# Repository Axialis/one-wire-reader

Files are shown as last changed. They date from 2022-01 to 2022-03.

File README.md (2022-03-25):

# One-Wire-Reader
One Wire Reader for 8 DS18B20 sensors on DS2482-100 (Maxim Integrated).
Addresses are written to non-volatile memory 

Schematic (KiCad):
OneWireReader

Photo:



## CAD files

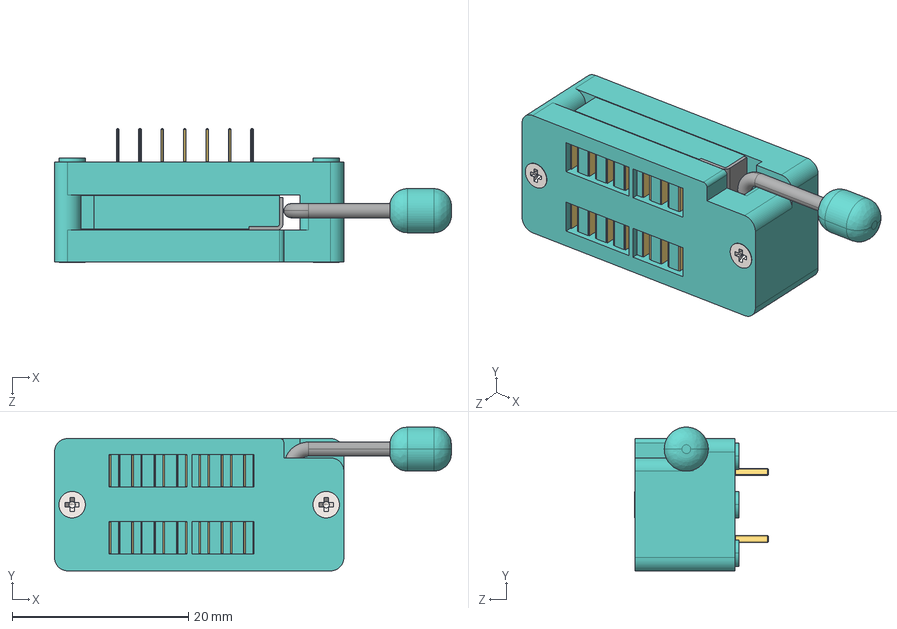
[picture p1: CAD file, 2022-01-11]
HW/3Dmodels/ZIF-Socket-14-pin.STEP
45.0 x 16.3 x 15.2 mm
Screw-002
Screw-001
Push-Bar
User_Library-ZIFF_14_Fillet008
User_Library-ZIFF_14_Fillet007
User_Library-ZIFF_14_Fusion008
User_Library-ZIFF_14_Cut002

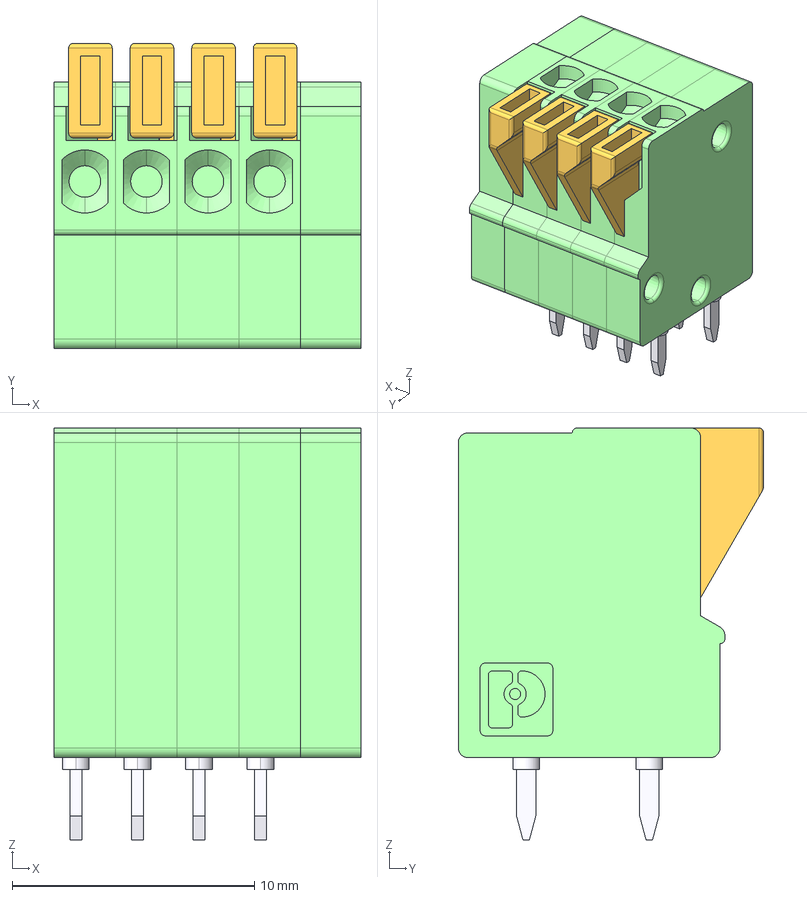
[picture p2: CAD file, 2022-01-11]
HW/3Dmodels/pxc_1789595_02_FFKDSA1-V-2-54-4_3D.stp
12.7 x 12.6 x 17.0 mm
ffkds-v-2.54.2 x 4
dkl-ffkds

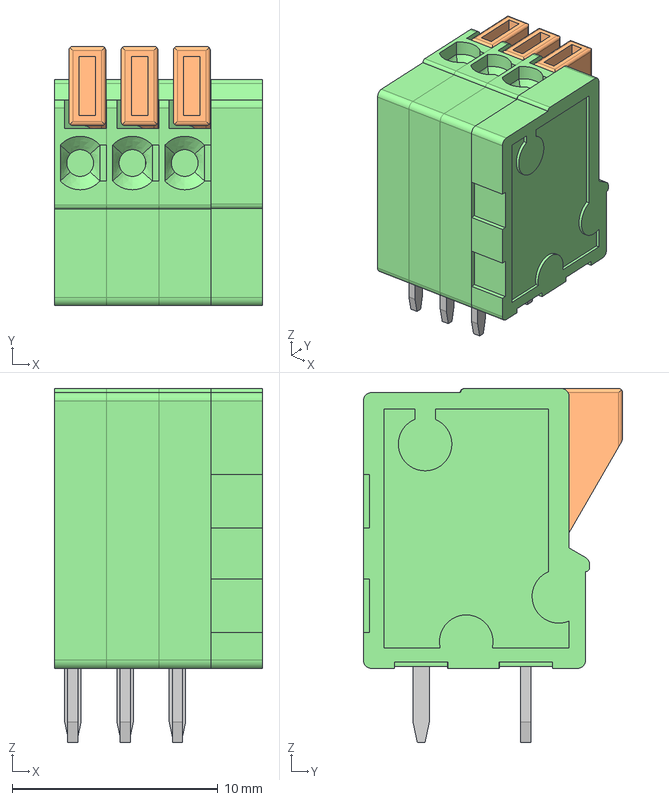
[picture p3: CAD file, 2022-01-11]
HW/3Dmodels/pxc_1789320_02_FFKDSA1-V-2-54-3_3D.stp
10.1 x 12.6 x 17.2 mm
LP_FFKDS_V_2_54_3_60.1.2 x 6
AC_FFKDS_2_54_WIPPE x 3
PK_FFKDS_V_2_54_GEH x 3
DK_D_FFKDS_2_54_DKL

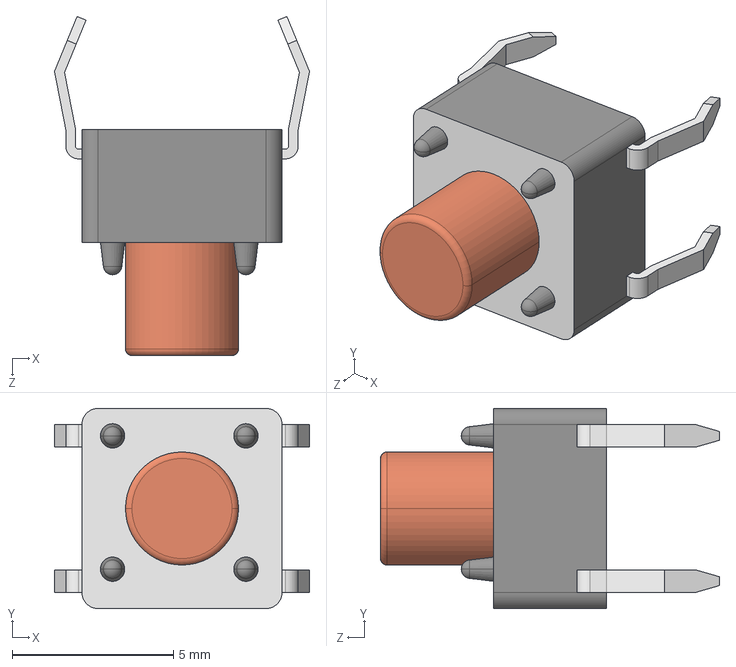
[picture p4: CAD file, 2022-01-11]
HW/3Dmodels/tactile dts-63k.step
7.90 x 6.20 x 10.5 mm

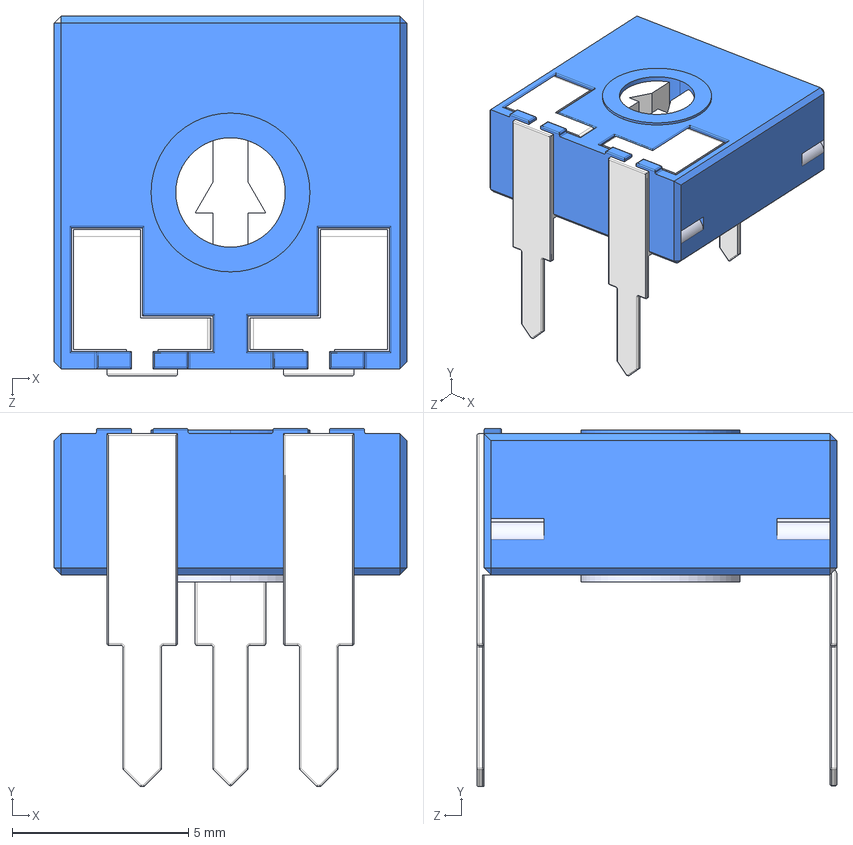
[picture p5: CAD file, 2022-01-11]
HW/3Dmodels/CA9V.step
10.0 x 10.2 x 10.2 mm

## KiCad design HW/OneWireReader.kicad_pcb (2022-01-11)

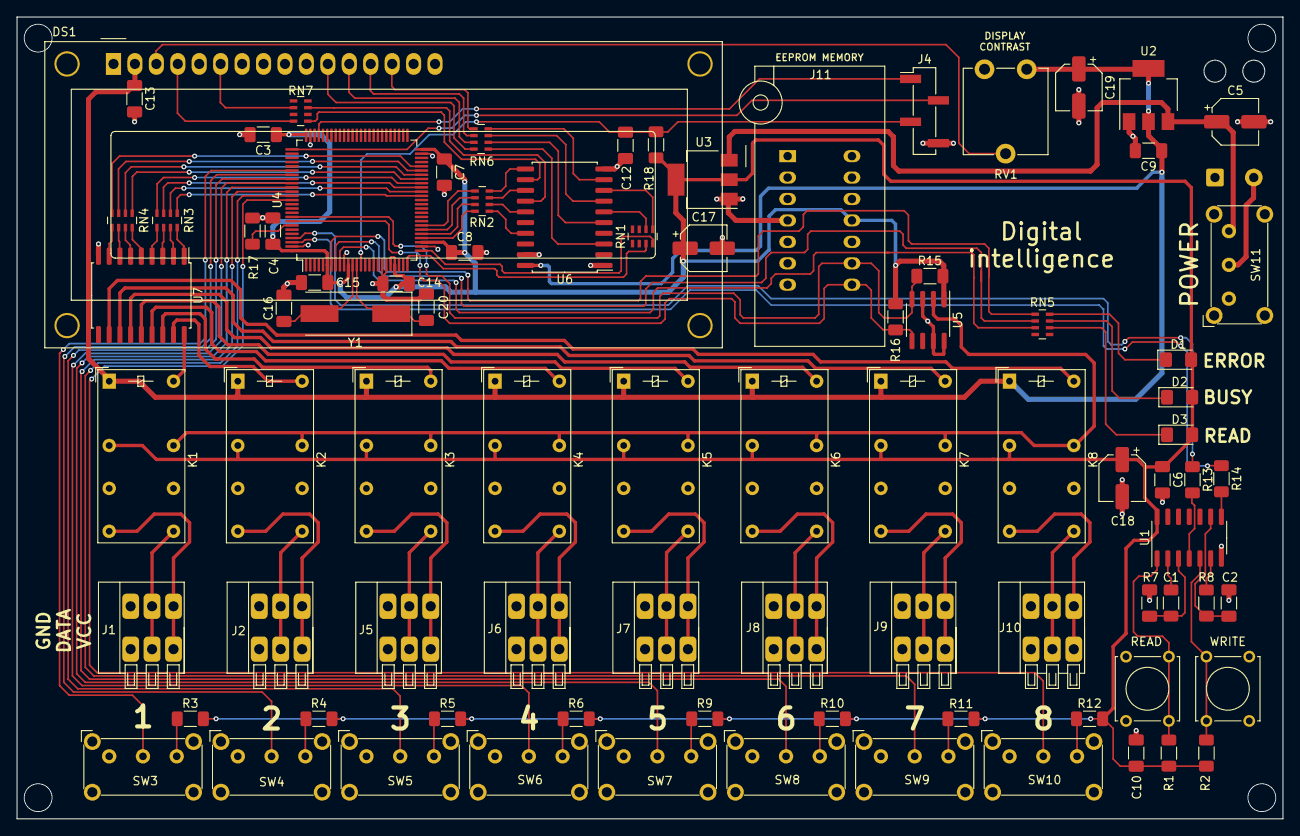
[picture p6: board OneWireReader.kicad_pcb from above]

Board: 2 copper layers, 150.0 x 95.0 mm, 87 parts (1 on the bottom side), 111 nets.

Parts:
C1, C2, C3, C4, C6, C7, C8, C9, C10, C12, C13, C14, C15: 100n; C_1206_3216Metric_Pad1.33x1.80mm_HandSolder
C5, C17, C18, C19: 10uF x16V; CP_Elec_5x5.4
C16, C20: 22p; C_1206_3216Metric_Pad1.33x1.80mm_HandSolder
D1, D2, D3: LED; LED_1206_3216Metric_Pad1.42x1.75mm_HandSolder
DS1: WC1602A
J1, J2, J5, J6, J7, J8, J9, J10: DG141V-2.54-03P-14-00A(H)
J3: Wire; SolderWire-0.5sqmm_1x02_P4.6mm_D0.9mm_OD2.1mm_Relief
J4: Programming; PinHeader_1x04_P2.54mm_Vertical_SMD_Pin1Left
J11: ZIF-14 KLS7-SK-22H13-1-S; DIP_Socket-14_W4.3_W5.08_W7.62_W10.16_W10.9_3M_214-3339-00-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
K1, K2, K3, K4, K5, K6, K7, K8: HFD2/005-S-D(FINDER-30.22); Relay_DPDT_Finder_30.22
R1, R2, R3, R4, R5, R6, R9, R10, R11, R12, R15, R16: 4k7; R_1206_3216Metric_Pad1.30x1.75mm_HandSolder
R7, R8, R13, R14: 220; R_1206_3216Metric_Pad1.30x1.75mm_HandSolder
R17, R18: 100k; R_1206_3216Metric_Pad1.30x1.75mm_HandSolder
READ: SW_Push; SW_Tactile_Straight_KSL0Axx1LFTR
RN1, RN2, RN3, RN4, RN5, RN6, RN7: 220; R_Array_Concave_4x0603
RV1: 10k; Potentiometer_ACP_CA9-V10_Vertical
SW3, SW4, SW5, SW6, SW7, SW8, SW9, SW10, SW11: KLS7-SK-22H13-1-S; SW_E-Switch_EG1224_SPDT_Angled
U1: 74HC14; SO-14_3.9x8.65mm_P1.27mm
U2: AZ1117-5.0; SOT-223-3_TabPin2
U3: AZ1117-3.3; SOT-223-3_TabPin2
U4: STM32F105VCTx; LQFP-100_14x14mm_P0.5mm
U5: DS2482S-100; SOIC-8_3.9x4.9mm_P1.27mm
U6: 74HCT244; SOIC-20W_7.5x12.8mm_P1.27mm
U7: ULN2803A; SOIC-18W_7.5x11.6mm_P1.27mm
WRITE: SW_Push; SW_Tactile_Straight_KSL0Axx1LFTR
Y1: 8MHz; Crystal_SMD_HC49-SD

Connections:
3V3: C3.1, C4.1, C6.1, C7.1, C8.1, C10.1, C14.1, C15.1, C17.1, C18.1, D1.2, D2.2, D3.2, J11.11, K1.11, K2.11, K3.11, K4.11, K5.11, K6.11, K7.11, K8.11, R1.2, R2.2, R3.2, R4.2, R5.2, R6.2, R9.2, R10.2, R11.1, R12.2, R15.2, R16.2, R18.2, U1.14, U3.2, U4.6, U4.11, U4.21, U4.22, U4.28, U4.50, U4.75, U4.100, U5.1
5V: C9.1, C13.1, C19.1, DS1.2, K1.A1, K2.A1, K3.A1, K4.A1, K5.A1, K6.A1, K7.A1, K8.A1, RV1.3, U2.2, U6.20
/BOOT: R17.2, U4.94
/BTN_1: R13.1, U4.97
/BTN_2: R14.1, U4.98
/DS_1: RN3.1, U4.39
/DS_2: RN3.2, U4.40
/DS_3: RN3.3, U4.41
/DS_4: RN3.4, U4.42
/DS_5: RN4.1, U4.43
/DS_6: RN4.2, U4.44
/DS_7: RN4.3, U4.45
/DS_8: RN4.4, U4.46
/NRST: C12.1, J4.3, R18.1, U4.14
/OSC1: C16.1, U4.12, Y1.2
/OSC2: C20.1, U4.13, Y1.1
/OneWire: K1.21, K2.21, K3.21, K4.21, K5.21, K6.21, K7.21, K8.21, U5.2
/Rel_1: K1.A2, U7.18
/Rel_2: K2.A2, U7.17
/Rel_3: K3.A2, U7.16
/Rel_4: K4.A2, U7.15
/Rel_5: K5.A2, U7.14
/Rel_6: K6.A2, U7.13
/Rel_7: K7.A2, U7.12
/Rel_8: K8.A2, U7.11
/SCL: J11.9, R15.1, U4.92, U5.4
/SDA: J11.8, R16.1, U4.93, U5.5
/SNS_1: SW3.2, U4.81
/SNS_2: SW4.2, U4.82
/SNS_3: SW5.2, U4.83
/SNS_4: SW6.2, U4.84
/SNS_5: SW7.2, U4.85
/SNS_6: SW8.2, U4.86
/SNS_7: SW9.2, U4.87
/SNS_8: SW10.2, U4.88
/SWCLK: J4.2, U4.76
/SWDIO: J4.1, U4.72
GND: C1.1, C2.1, C3.2, C4.2, C5.2, C6.2, C7.2, C8.2, C9.2, C10.2, C12.2, C13.2, C14.2, C15.2, C16.2, C17.2, C18.2, C19.2, C20.2, DS1.1, DS1.5, J1.3, J2.3, J3.1, J4.4, J5.3, J6.3, J7.3, J8.3, J9.3, J10.3, J11.4, J11.5, J11.6, J11.7, J11.10, R17.1, READ.1, RV1.1, SW3.1, SW4.1, SW5.1, SW6.1, SW7.1, SW8.1, SW9.1, SW10.1, U1.7, U2.1, U3.1, U4.10, U4.19, U4.20, U4.27, U4.49, U4.74, U4.99, U5.3, U5.7, U5.8, U6.1, U6.10, U6.19, U7.9, WRITE.1
unnamed: C1.2, R7.1, U1.3
unnamed: C2.2, R8.1, U1.9
unnamed: C5.1, SW11.3, U2.3, U3.3
unnamed: D1.1, RN5.8
unnamed: D2.1, RN5.7
unnamed: D3.1, RN5.6
unnamed: DS1.3, RV1.2
unnamed: DS1.4, RN7.8
unnamed: DS1.6, RN7.6
unnamed: DS1.11, RN6.8
unnamed: DS1.12, RN6.7
unnamed: DS1.13, RN6.6
unnamed: DS1.14, RN6.5
unnamed: J1.1, K1.14
unnamed: J1.2, K1.24
unnamed: J2.1, K2.14
unnamed: J2.2, K2.24
unnamed: J3.2, SW11.2
unnamed: J5.1, K3.14
unnamed: J5.2, K3.24
unnamed: J6.1, K4.14
unnamed: J6.2, K4.24
unnamed: J7.1, K5.14
unnamed: J7.2, K5.24
unnamed: J8.1, K6.14
unnamed: J8.2, K6.24
unnamed: J9.1, K7.14
unnamed: J9.2, K7.24
unnamed: J10.1, K8.14
unnamed: J10.2, K8.24
unnamed: R1.1, READ.2, U1.1
unnamed: R2.1, U1.5, WRITE.2
unnamed: R3.1, SW3.3
unnamed: R4.1, SW4.3
unnamed: R5.1, SW5.3
unnamed: R6.1, SW6.3
unnamed: R7.2, U1.2
unnamed: R8.2, U1.6
unnamed: R9.1, SW7.3
unnamed: R10.1, SW8.3
unnamed: R11.2, SW9.3
unnamed: R12.1, SW10.3
unnamed: R13.2, U1.4
unnamed: R14.2, U1.8
unnamed: RN1.3, U4.25
unnamed: RN1.4, U4.26
unnamed: RN1.5, U6.8
unnamed: RN1.6, U6.6
unnamed: RN2.1, U4.32
unnamed: RN2.2, U4.31
unnamed: RN2.3, U4.30
unnamed: RN2.4, U4.29
unnamed: RN2.5, U6.17
unnamed: RN2.6, U6.15
unnamed: RN2.7, U6.13
unnamed: RN2.8, U6.11
unnamed: RN3.5, U7.4
unnamed: RN3.6, U7.3
unnamed: RN3.7, U7.2
unnamed: RN3.8, U7.1
unnamed: RN4.5, U7.8
unnamed: RN4.6, U7.7
unnamed: RN4.7, U7.6
unnamed: RN4.8, U7.5
unnamed: RN5.1, U4.7
unnamed: RN5.2, U4.8
unnamed: RN5.3, U4.9
unnamed: RN6.1, U6.3
unnamed: RN6.2, U6.5
unnamed: RN6.3, U6.7
unnamed: RN6.4, U6.9
unnamed: RN7.1, U6.12
unnamed: RN7.3, U6.14

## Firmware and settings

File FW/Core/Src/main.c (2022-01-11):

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
/* Includes ------------------------------------------------------------------*/
#include "main.h"
#include "i2c.h"
#include "gpio.h"

/* USER CODE BEGIN Includes */
#include "lcd.h"
#include "macro.h"
#include "memory.h"
#include "DS2482.h"



/* USER CODE END Includes */


void SystemClock_Config(void);
/* USER CODE BEGIN PFP */
void ErrorLed(uint8_t status);
void BusyLed(uint8_t status);
void ReadLed(uint8_t status);
void SelectChannels();
void DrawSelectChannel();
void DrawAnimation();
void RelayControl();
void Rel(int number);
void WriteMemory();
void ReadOWDevice();
void AddressMenu(uint8_t channel);
void StatusPercent(uint8_t per);
uint8_t LinePosition(uint8_t ch);

/* USER CODE END PFP */

/* USER CODE BEGIN 0 */
typedef enum
{
	ON = 1,
	OFF = 0
} LedState;


Lcd_HandleTypeDef lcd;



uint8_t channel[7];
uint8_t sensor[8][8] = {0x00};
uint8_t key = 0;
uint8_t menuposstart = 0;

/* USER CODE END 0 */

/**
 * @brief  The application entry point.
 * @retval int
 */
int main(void)
{
	/* MCU Configuration--------------------------------------------------------*/

	/* Reset of all peripherals, Initializes the Flash interface and the Systick. */
	HAL_Init();

	/* Configure the system clock */
	SystemClock_Config();

	/* Initialize all configured peripherals */
	MX_GPIO_Init();
	MX_I2C1_Init();
	/* USER CODE BEGIN 2 */
	HAL_Delay(100);
	Lcd_PortType ports[] = {
			D4_GPIO_Port, D5_GPIO_Port, D6_GPIO_Port, D7_GPIO_Port
	};

	Lcd_PinType pins[] = {D4_Pin, D5_Pin, D6_Pin, D7_Pin};



	lcd = Lcd_create(ports, pins, RS_GPIO_Port, RS_Pin, E_GPIO_Port, E_Pin, LCD_4_BIT_MODE);

	Lcd_cursor(&lcd, 0,3);
	Lcd_string(&lcd, "TENDO 4/8");
	Lcd_cursor(&lcd, 1,0);
	Lcd_string(&lcd, "ONE WIRE READER");


	Lcd_clear(&lcd);

	DS2842Reset();
	DS2842Configuration();

	ErrorLed(OFF);
	BusyLed(OFF);
	ReadLed(OFF);


	/* USER CODE END 2 */

	/* Infinite loop */
	/* USER CODE BEGIN WHILE */
	while (1)
	{
		/* USER CODE END WHILE */

		/* USER CODE BEGIN 3 */

		switch (key) {
		case 0:

			Lcd_cursor(&lcd, 0,0);
			Lcd_string(&lcd, "SELECT CHANNELS");
			SelectChannels();
			DrawSelectChannel();
			if(HAL_GPIO_ReadPin(GPIOE, GPIO_PIN_0) == 0) //read
			{
				key = 1;
			}

			if(HAL_GPIO_ReadPin(GPIOE, GPIO_PIN_1) == 0) //write
			{
				key = 9;
			}

			break;

		case 1:
			Lcd_clear(&lcd);
			key = 2;
			break;

		case 2:
			DrawAnimation();
			key = 5;
			break;

		case 3:
			Lcd_clear(&lcd);
			key = 4;
			break;

		case 4:
			DrawAnimation();
			key = 7;
			break;

		case 5:
			Lcd_clear(&lcd);
			key = 6;
			break;

		case 6:
			Lcd_cursor(&lcd, 0,0);
			Lcd_string(&lcd, "Press READ to");
			Lcd_cursor(&lcd, 1,0);
			Lcd_string(&lcd, "continue");
			for(;;)
			{
				Lcd_cursor(&lcd, 1,15);
				Lcd_string(&lcd, ">");
				if(HAL_GPIO_ReadPin(GPIOE, GPIO_PIN_0) == 0) //read
				{
					ReadOWDevice();
					key = 7;
					break;
				}
				HAL_Delay(150);
				Lcd_cursor(&lcd, 1,15);
				Lcd_string(&lcd, " ");
				if(HAL_GPIO_ReadPin(GPIOE, GPIO_PIN_0) == 0) //read
				{
					ReadOWDevice();
					key = 7;
					break;
				}
				HAL_Delay(150);
			}

			break;

		case 7:
			AddressMenu(menuposstart);
			key = 8;
			break;

		case 8:

			if(HAL_GPIO_ReadPin(GPIOE, GPIO_PIN_0) == 0) //<R
			{
				if(menuposstart != 0)
				{
					HAL_Delay(150);
					menuposstart = menuposstart - 1;
					key = 7;
				}
			}

			if(HAL_GPIO_ReadPin(GPIOE, GPIO_PIN_1) == 0) //W>
			{
				if(menuposstart != 9)
				{
					HAL_Delay(150);
					menuposstart = menuposstart + 1;
					key = 7;
				}
				if(menuposstart == 9)
				{
					menuposstart = 0;
					Lcd_clear(&lcd);
					for(int k = 0; k<8; k++)
					{
						for(int m = 0; m<8; m++)
						{
							sensor[k][m] = 0;
						}
					}
					key = 0;
				}
			}
			break;
			//-----------------------------------------------------WRITE TO MEMORY--------------------------------------------//
		case 9:
			Lcd_clear(&lcd);
			key = 10;
			break;

		case 10:
			Lcd_cursor(&lcd, 0,0);
			Lcd_string(&lcd, "Insert IC memory ");
			Lcd_cursor(&lcd, 1,0);
			Lcd_string(&lcd, "and press WRITE");
			for(;;)
			{
				Lcd_cursor(&lcd, 1,15);
				Lcd_string(&lcd, ">");
				if(HAL_GPIO_ReadPin(GPIOE, GPIO_PIN_1) == 0) //write
				{
					key = 11;
					break;
				}
				HAL_Delay(150);
				Lcd_cursor(&lcd, 1,15);
				Lcd_string(&lcd, " ");
				if(HAL_GPIO_ReadPin(GPIOE, GPIO_PIN_1) == 0) //write
				{
					key = 11;
					break;
				}
				HAL_Delay(150);
			}
			break;

		case 11:
			Lcd_clear(&lcd);
			key = 12;
			break;

		case 12:

			if(HAL_I2C_IsDeviceReady(&hi2c1, 0xA0, 1, HAL_MAX_DELAY) != HAL_OK)
			{
				ErrorLed(ON);
				Lcd_cursor(&lcd, 0,0);
				Lcd_string(&lcd, "NO MEMORY IC");
				Lcd_cursor(&lcd, 1,0);
				Lcd_string(&lcd, "Check slot");
				key = 13;
			}
			else
			{
				ErrorLed(OFF);
				key = 15;
			}
			break;

		case 13:

			if(HAL_I2C_IsDeviceReady(&hi2c1, 0xA0, 1, HAL_MAX_DELAY) != HAL_OK)
			{
				key = 12;
			}
			else
			{
				key = 14;
			}
			break;

		case 14:
			Lcd_clear(&lcd);
			key = 15;
			break;

		case 15:
			ErrorLed(OFF);
			Lcd_cursor(&lcd, 0,0);
			Lcd_string(&lcd, "OK");
			Lcd_cursor(&lcd, 1,0);
			Lcd_string(&lcd, "Press WRITE");
			for(;;)
			{
				Lcd_cursor(&lcd, 1,15);
				Lcd_string(&lcd, ">");
				if(HAL_GPIO_ReadPin(GPIOE, GPIO_PIN_1) == 0) //read
				{
					key = 16;
					break;
				}
				HAL_Delay(150);
				Lcd_cursor(&lcd, 1,15);
				Lcd_string(&lcd, " ");
				if(HAL_GPIO_ReadPin(GPIOE, GPIO_PIN_1) == 0) //read
				{
					key = 16;
					break;
				}
				HAL_Delay(150);
			}
			break;

		case 16:
			Lcd_clear(&lcd);
			key = 17;
			break;

		case 17:
			ReadOWDevice();
			WriteMemory();
			key = 18;
			break;

		case 18:
			Lcd_clear(&lcd);
			Lcd_cursor(&lcd, 0,0);
			Lcd_string(&lcd, "OK! Press 'W' to");
			Lcd_cursor(&lcd, 1,0);
			Lcd_string(&lcd, "return Main Menu");
			key = 19;
			break;

		case 19:
				if(HAL_GPIO_ReadPin(GPIOE, GPIO_PIN_1) == 0) //read
				{
					Lcd_clear(&lcd);
					key = 0;
					break;
				}
			break;


		}

	}
	/* USER CODE END 3 */
}

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
/* USER CODE BEGIN 4 */

void ErrorLed(uint8_t status)
{
	if(status == 0)
	{
		HAL_GPIO_WritePin(GPIOC, GPIO_PIN_13, GPIO_PIN_SET);
	}
	else
	{
		HAL_GPIO_WritePin(GPIOC, GPIO_PIN_13, GPIO_PIN_RESET);
	}
}

void BusyLed(uint8_t status)
{
	if(status == 0)
	{
		HAL_GPIO_WritePin(GPIOC, GPIO_PIN_14, GPIO_PIN_SET);
	}
	else
	{
		HAL_GPIO_WritePin(GPIOC, GPIO_PIN_14, GPIO_PIN_RESET);
	}
}

void ReadLed(uint8_t status)
{
	if(status == 0)
	{
		HAL_GPIO_WritePin(GPIOC, GPIO_PIN_15, GPIO_PIN_SET);
	}
	else
	{
		HAL_GPIO_WritePin(GPIOC, GPIO_PIN_15, GPIO_PIN_RESET);
	}
}

void SelectChannels()
{
	if(HAL_GPIO_ReadPin(GPIOD, GPIO_PIN_0) == 0)
	{
		channel[0] = 1;
	}
	else
	{
		channel[0] = 0;
	}
	if(HAL_GPIO_ReadPin(GPIOD, GPIO_PIN_1) == 0)
	{
		channel[1] = 1;
	}
	else
	{
		channel[1] = 0;
	}
	if(HAL_GPIO_ReadPin(GPIOD, GPIO_PIN_2) == 0)
	{
		channel[2] = 1;
	}
	else
	{
		channel[2] = 0;
	}
	if(HAL_GPIO_ReadPin(GPIOD, GPIO_PIN_3) == 0)
	{
		channel[3] = 1;
	}
	else
	{
		channel[3] = 0;
	}
	if(HAL_GPIO_ReadPin(GPIOD, GPIO_PIN_4) == 0)
	{
		channel[4] = 1;
	}
	else
	{
		channel[4] = 0;
	}
	if(HAL_GPIO_ReadPin(GPIOD, GPIO_PIN_5) == 0)
	{
		channel[5] = 1;
	}
	else
	{
		channel[5] = 0;
	}
	if(HAL_GPIO_ReadPin(GPIOD, GPIO_PIN_6) == 0)
	{
		channel[6] = 1;
	}
	else
	{
		channel[6] = 0;
	}
	if(HAL_GPIO_ReadPin(GPIOD, GPIO_PIN_7) == 0)
	{
		channel[7] = 1;
	}
	else
	{
		channel[7] = 0;
	}
}

void DrawSelectChannel()
{
	if(channel[0] == 0)
	{
		Lcd_cursor(&lcd, 1, 0);
		Lcd_string(&lcd, "1");
	}
	else
	{
		Lcd_cursor(&lcd, 1, 0);
		Lcd_string(&lcd, " ");
	}

	if(channel[1] == 0)
	{
		Lcd_cursor(&lcd, 1, 2);
		Lcd_string(&lcd, "2");
	}
	else
	{
		Lcd_cursor(&lcd, 1, 2);
		Lcd_string(&lcd, " ");
	}

	if(channel[2] == 0)
	{
		Lcd_cursor(&lcd, 1, 4);
		Lcd_string(&lcd, "3");
	}
	else
	{
		Lcd_cursor(&lcd, 1, 4);
		Lcd_string(&lcd, " ");
	}

	if(channel[3] == 0)
	{
		Lcd_cursor(&lcd, 1, 6);
		Lcd_string(&lcd, "4");
	}
	else
	{
		Lcd_cursor(&lcd, 1, 6);
		Lcd_string(&lcd, " ");
	}

	if(channel[4] == 0)
	{
		Lcd_cursor(&lcd, 1, 8);
		Lcd_string(&lcd, "5");
	}
	else
	{
		Lcd_cursor(&lcd, 1, 8);
		Lcd_string(&lcd, " ");
	}

	if(channel[5] == 0)
	{
		Lcd_cursor(&lcd, 1, 10);
		Lcd_string(&lcd, "6");
	}
	else
	{
		Lcd_cursor(&lcd, 1, 10);
		Lcd_string(&lcd, " ");
	}

	if(channel[6] == 0)
	{
		Lcd_cursor(&lcd, 1, 12);
		Lcd_string(&lcd, "7");
	}
	else
	{
		Lcd_cursor(&lcd, 1, 12);
		Lcd_string(&lcd, " ");
	}

	if(channel[7] == 0)
	{
		Lcd_cursor(&lcd, 1, 14);
		Lcd_string(&lcd, "8");
	}
	else
	{
		Lcd_cursor(&lcd, 1, 14);
		Lcd_string(&lcd, " ");
	}
}

void DrawAnimation()
{
	for (int i = 0; i<15; i++)
	{
		Lcd_cursor(&lcd, 0,i);
		Lcd_string(&lcd, ">");
		HAL_Delay(10);
	}
	for (int i = 15; i>0; i--)
	{
		Lcd_cursor(&lcd, 1,i);
		Lcd_string(&lcd, "<");
		HAL_Delay(10);
	}
}

void RelayControl()
{
	for(int i = 0; i<7; i++)
	{
		if(channel[i] == 0)
		{
			Rel(i);
		}
	}
}

void Rel(int number)
{
	switch (number) {
	case 0:
		REL_1(ON); REL_2(OFF); REL_3(OFF); REL_4(OFF); REL_5(OFF); REL_6(OFF); REL_7(OFF); REL_8(OFF);
		break;
	case 1:
		REL_1(OFF); REL_2(ON); REL_3(OFF); REL_4(OFF); REL_5(OFF); REL_6(OFF); REL_7(OFF); REL_8(OFF);
		break;
	case 2:
		REL_1(OFF); REL_2(OFF); REL_3(ON); REL_4(OFF); REL_5(OFF); REL_6(OFF); REL_7(OFF); REL_8(OFF);
		break;
	case 3:
		REL_1(OFF); REL_2(OFF); REL_3(OFF); REL_4(ON); REL_5(OFF); REL_6(OFF); REL_7(OFF); REL_8(OFF);
		break;
	case 4:
		REL_1(OFF); REL_2(OFF); REL_3(OFF); REL_4(OFF); REL_5(ON); REL_6(OFF); REL_7(OFF); REL_8(OFF);
		break;
	case 5:
		REL_1(OFF); REL_2(OFF); REL_3(OFF); REL_4(OFF); REL_5(OFF); REL_6(ON); REL_7(OFF); REL_8(OFF);
		break;
	case 6:
		REL_1(OFF); REL_2(OFF); REL_3(OFF); REL_4(OFF); REL_5(OFF); REL_6(OFF); REL_7(ON); REL_8(OFF);
		break;
	case 7:
		REL_1(OFF); REL_2(OFF); REL_3(OFF); REL_4(OFF); REL_5(OFF); REL_6(OFF); REL_7(OFF); REL_8(ON);
		break;
	default:
		REL_1(OFF); REL_2(OFF); REL_3(OFF); REL_4(OFF); REL_5(OFF); REL_6(OFF); REL_7(OFF); REL_8(OFF);
		break;
	}
}

void WriteMemory()
{
	uint8_t xpos = 0x00;
	BusyLed(ON);
	for(int k = 0; k<8; k++)
	{
		if(channel[k] == 0)
		{
			StatusPercent(k);
		}
		xpos = LinePosition(k);
		for(int i = 0; i<8; i++)
		{
			{
				if(channel[k] == 0)
				{
					writeToMemory(sensor[k][i], 0x00 , xpos);
					xpos = xpos+1;
				}
			}
		}
	}

	Lcd_clear(&lcd);
	Lcd_cursor(&lcd, 1, 6);
	Lcd_string(&lcd, "100%");
	BusyLed(OFF);

}

void ReadOWDevice()
{
	ReadLed(ON);
	Lcd_clear(&lcd);
	for(int k = 0; k<8; k++)
	{
		if(channel[k] == 0)
		{
			Rel(k);
			HAL_Delay(500);
			OWReset();
			OWWriteByte(0x33);
		}

		if(channel[k] == 0)
		{

			for(int i = 0; i<8; i++)
			{
				sensor[k][i] = OWReadByte();
			}

			DS2842Reset();
			OWReset();
		}
	}
	ReadLed(OFF);

}

void AddressMenu(uint8_t channel)
{
	char str[8];
	char ch[2];

	if(channel != 8)
	{
		Lcd_clear(&lcd);
		Lcd_cursor(&lcd, 0, 0);

		for(int i = 0; i<8; i++)
		{
			sprintf(str, "%02X" , sensor[channel][i]);
			Lcd_string(&lcd, str);
		}

		sprintf(ch, "%i" , channel+1);

		Lcd_cursor(&lcd, 1, 3);
		Lcd_string(&lcd, "Channel #");
		Lcd_string(&lcd, ch);
		Lcd_cursor(&lcd, 1, 14);
		Lcd_string(&lcd, "W>");
		if(channel != 0)
		{
			Lcd_cursor(&lcd, 1,0);
			Lcd_string(&lcd, "<R");
		}
	}


	if(channel == 8)
	{
		Lcd_clear(&lcd);
		Lcd_cursor(&lcd, 0, 0);
		Lcd_string(&lcd, "Exit to menu?");
		Lcd_cursor(&lcd, 1, 0);
		Lcd_string(&lcd, "<R(No)");
		Lcd_cursor(&lcd, 1, 9);
		Lcd_string(&lcd, "(Yes)W>");
	}
}

uint8_t LinePosition(uint8_t ch)
{
	return (8*ch);
}

void StatusPercent(uint8_t per)
{
	if(per == 0)
	{
		Lcd_clear(&lcd);
		Lcd_cursor(&lcd, 1, 6);
		Lcd_string(&lcd, "12.5%");
	}
	if(per == 1)
	{
		Lcd_clear(&lcd);
		Lcd_cursor(&lcd, 1, 6);
		Lcd_string(&lcd, "25%");
	}
	if(per == 3)
	{
		Lcd_clear(&lcd);
		Lcd_cursor(&lcd, 1, 6);
		Lcd_string(&lcd, "37.5%");
	}
	if(per == 3)
	{
		Lcd_clear(&lcd);
		Lcd_cursor(&lcd, 1, 6);
		Lcd_string(&lcd, "50%");
	}
	if(per == 4)
	{
		Lcd_clear(&lcd);
		Lcd_cursor(&lcd, 1, 6);
		Lcd_string(&lcd, "62.5%");
	}
	if(per == 5)
	{
		Lcd_clear(&lcd);
		Lcd_cursor(&lcd, 1, 6);
		Lcd_string(&lcd, "75%");
	}
	if(per == 6)
	{
		Lcd_clear(&lcd);
		Lcd_cursor(&lcd, 1, 6);
		Lcd_string(&lcd, "87.5%");
	}
	if(per == 7)
	{
		Lcd_clear(&lcd);
		Lcd_cursor(&lcd, 1, 6);
		Lcd_string(&lcd, "100%");
	}
}

/* USER CODE END 4 */
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


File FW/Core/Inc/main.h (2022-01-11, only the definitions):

#define E_Pin GPIO_PIN_2
#define E_GPIO_Port GPIOA
#define RS_Pin GPIO_PIN_3
#define RS_GPIO_Port GPIOA
#define D4_Pin GPIO_PIN_4
#define D4_GPIO_Port GPIOA
#define D5_Pin GPIO_PIN_5
#define D5_GPIO_Port GPIOA
#define D6_Pin GPIO_PIN_6
#define D6_GPIO_Port GPIOA
#define D7_Pin GPIO_PIN_7
#define D7_GPIO_Port GPIOA

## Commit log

2022-01-11 init: add FW reader code
    [Reader Debug.cfg]
2022-01-11 add: HW files
    [CA9V.step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]

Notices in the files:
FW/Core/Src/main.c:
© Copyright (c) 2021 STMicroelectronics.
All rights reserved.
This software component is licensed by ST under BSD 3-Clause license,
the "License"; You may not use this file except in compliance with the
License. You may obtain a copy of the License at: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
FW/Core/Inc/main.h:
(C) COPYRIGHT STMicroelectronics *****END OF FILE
